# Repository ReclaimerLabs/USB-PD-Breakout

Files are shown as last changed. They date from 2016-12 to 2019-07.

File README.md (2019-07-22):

# Introduction

This board features an FUSB302B as a Type-C Port Management (TCPM) chip. You can purchase one on [Tindie](https://www.tindie.com/products/ReclaimerLabs/usb-type-c-power-delivery-phy-breakout-board/). 

# Features

The FUSB302B is a fully-capable USB Power Delivery device. The power header is rated to 100 W (20 V at 5 A) if both Vbus pins are used along with two ground pins. The FUSB302B's max I2C clock frequency is 1 MHz. 

# Example Usage

Example code for use with Arduino can be found [here](https://github.com/graycatlabs/usb-c-arduino/tree/master/usb-c-demo). The [USB-C Explorer](https://github.com/ReclaimerLabs/USB-C-Explorer/tree/master/firmware/USB-C%20Explorer) also uses the same chip. 

Here are the connections you will need. 

* Breakout Pin -> Arduino Pin
* GND -> GND
* Vbus -> Vin (power to the Arduino, regulated down to +5V)
* Vpu -> IOREF (power for pullups for I2C and interrupt)
* VDD -> 3.3V (power for the FUSB302B)
* SDA -> SDA
* SCL -> SCL
* INT -> D12
* GND -> GND (for good measure)

# Questions, Comments, and Contributions

Pull requests are welcome. If you have questions or comments, you can email me directly at jason@reclaimerlabs.com.

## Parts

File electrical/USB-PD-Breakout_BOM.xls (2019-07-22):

Item # | Quantity | Reference | Type | Footprint | Manufacturer | Manufacturer Part Number | Supplier 1 | Supplier 1 Part Number
5 | 1 | C1 | SMD | Capacitors_SMD:C_1206 | Samsung Electro-Mechanics | CL31A106KAHNNNE | Digikey | 1276-1075-1-ND
6 | 2 | C2, C4 | SMD | Capacitors_SMD:C_0603 | Samsung Electro-Mechanics | CL10B104KB8NNNC | Digikey | 1276-1000-1-ND
7 | 1 | C3 | SMD | Capacitors_SMD:C_0805 | Samsung Electro-Mechanics | CL21B105KOFNNNG | Digikey | 1276-6471-1-ND
1 | 2 | C5, C6 | SMD | Capacitors_SMD:C_0603 | Yageo | CC0603KRX7R9BB471 | Digikey | 311-1078-1-ND
2 | 1 | J1 | SMD | Reclaimer_Labs:USB-C_Female_105450-0101 | Molex | 1054500101 | Digikey | WM12856CT-ND
8 | 1 | J2 | SMD | Reclaimer_Labs:USB_Micro-B_10118193 | Amphenol ICC (FCI) | 10118193-0001LF | Digikey | 609-4616-1-ND
9 | 1 | J3 | Thru-hole | Socket_Strips:Socket_Strip_Straight_2x03 | Amphenol ICC (FCI) | 67997-206HLF | Digikey | 609-3234-ND
10 | 1 | J4 | Thru-hole | Socket_Strips:Socket_Strip_Straight_1x08 | Amphenol ICC (FCI) | 77311-818-08LF | Digikey | 609-5130-ND
4 | 3 | R1, R2, R3 | SMD | Capacitors_SMD:C_0603 | Yageo | RC0603FR-074K7L | Digikey | 311-4.70KHRCT-ND
3 | 1 | U1 | SMD | Reclaimer_Labs:MLP_14 | ON Semiconductor | FUSB302BMPX | Digikey | FUSB302BMPXCT-ND

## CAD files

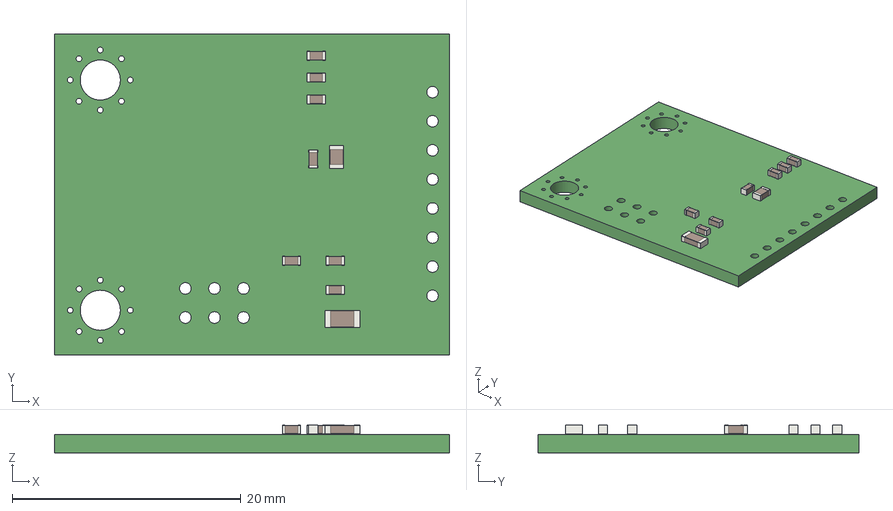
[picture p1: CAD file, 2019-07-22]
electrical/USB-PD-Breakout.step
34.5 x 28.0 x 2.43 mm
Socket_Strip_Straight_2x03
Socket_Strip_Straight_1x08_Pitch2.54mm

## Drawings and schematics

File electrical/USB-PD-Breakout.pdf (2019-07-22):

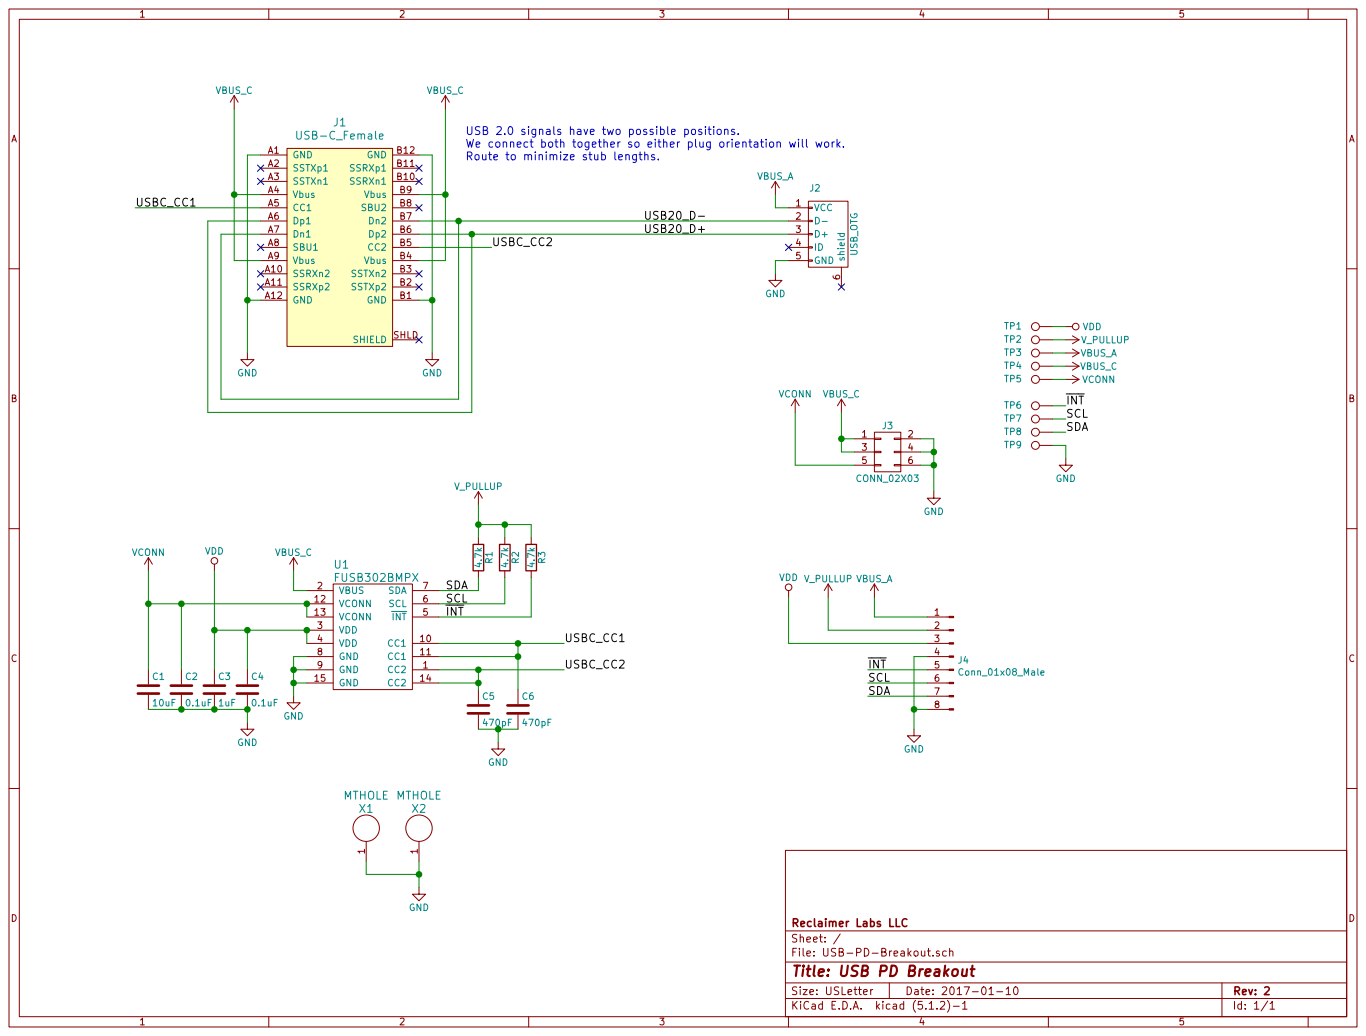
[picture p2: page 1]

V_PULLUP USB 2.0 signals have two possible positions.
We connect both together so either plug orientation will work.
Route to minimize stub lengths.

Id: 1/1 Title: USB PD Breakout File: USB-PD-Breakout.sch Sheet: / Reclaimer Labs LLC

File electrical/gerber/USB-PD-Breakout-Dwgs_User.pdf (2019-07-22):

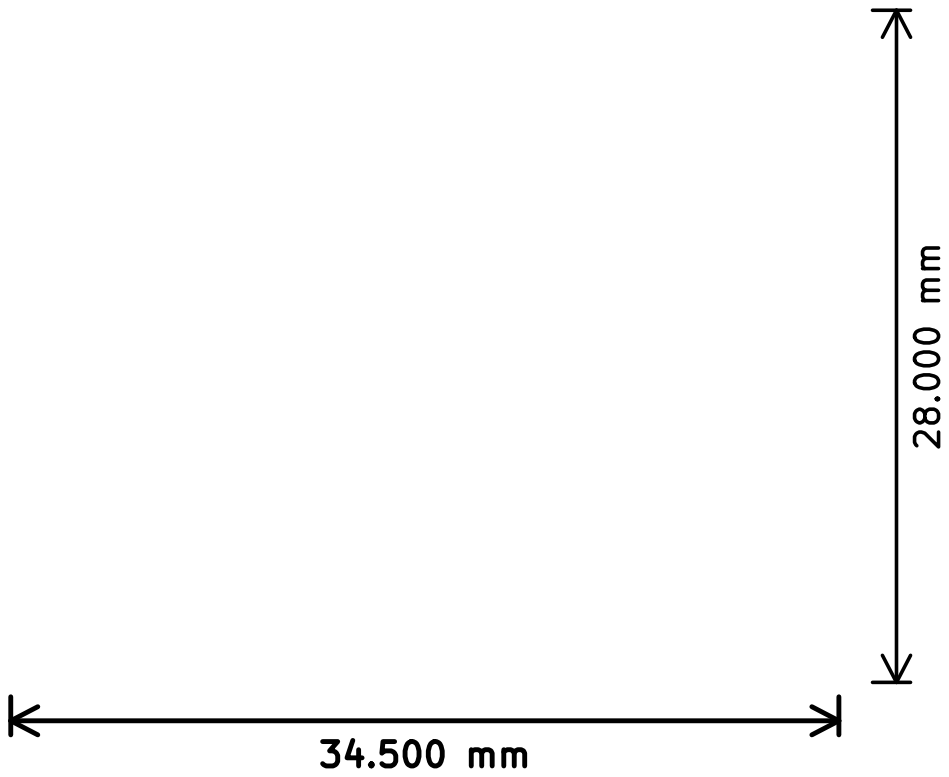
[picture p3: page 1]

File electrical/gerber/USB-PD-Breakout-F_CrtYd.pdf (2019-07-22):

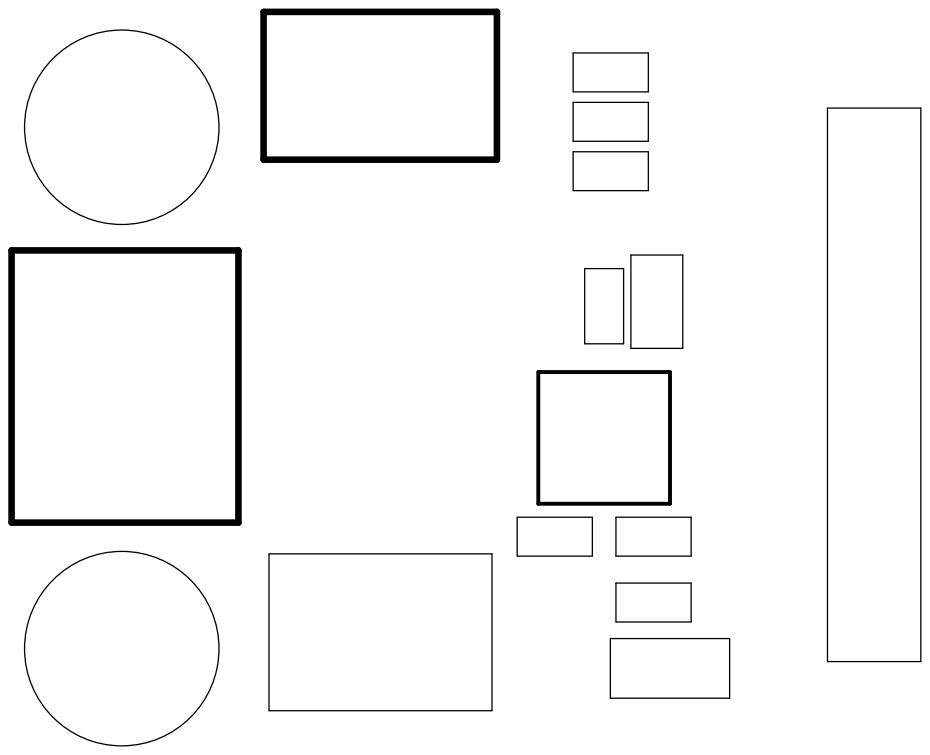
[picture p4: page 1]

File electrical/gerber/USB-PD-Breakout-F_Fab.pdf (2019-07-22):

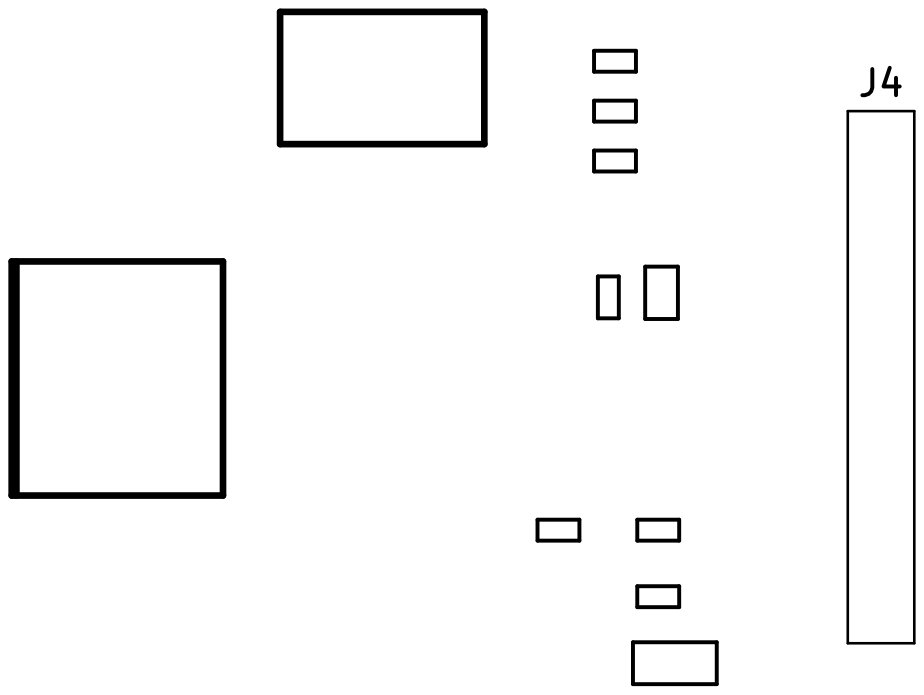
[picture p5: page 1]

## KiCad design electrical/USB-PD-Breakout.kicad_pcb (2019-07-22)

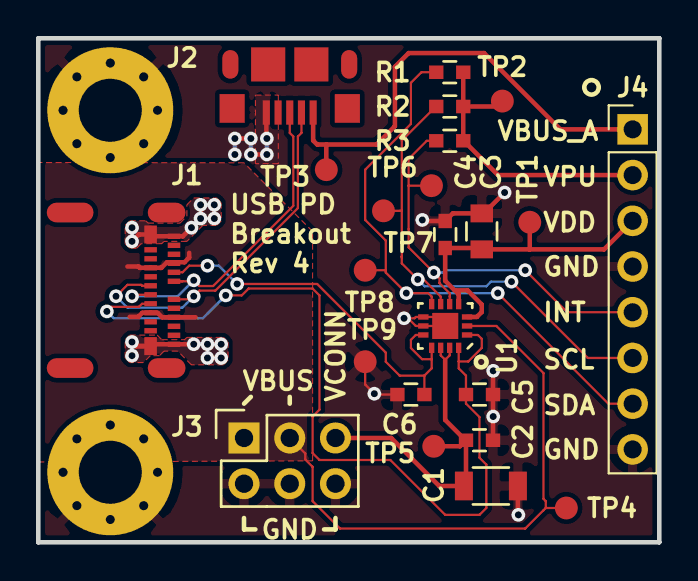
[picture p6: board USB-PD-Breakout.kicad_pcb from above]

Board: 2 copper layers, 34.5 x 28.0 mm, 25 parts (0 on the bottom side), 13 nets.

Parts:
C1: 10uF; C_1206
C2, C4: 0.1uF; C_0603
C3: 1uF; C_0805
C5, C6: 470pF; C_0603
J1: USB-C_Female; USB-C_Female_105450-0101
J2: USB_OTG; USB_Micro-B_10118193
J3: CONN_02X03; Socket_Strip_Straight_2x03
J4: Conn_01x08_Male; Socket_Strip_Straight_1x08_Pitch2.54mm
R1, R2, R3: 4.7k; C_0603
TP1, TP2, TP3, TP4, TP5, TP6, TP7, TP8, TP9: TEST_1P; TP
U1: FUSB302BMPX; MLP_14
X1, X2: MTHOLE; MountingHole_3.5mm_Pad_Via

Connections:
/SCL: J4.6, R2.2, TP7.1, U1.6
/SDA: J4.7, R1.2, TP8.1, U1.7
/USB20_D+: J1.A6, J1.B6, J2.3
/USB20_D-: J1.A7, J1.B7, J2.2
/USBC_CC1: C6.1, J1.A5, U1.10, U1.11
/USBC_CC2: C5.1, J1.B5, U1.1, U1.14
/~INT: J4.5, R3.2, TP6.1, U1.5
GND: C1.2, C2.2, C3.2, C4.2, C5.2, C6.2, J1.A1, J1.A12, J1.B1, J1.B12, J2.5, J3.2, J3.4, J3.6, J4.4, J4.8, TP9.1, U1.8, U1.9, U1.15, X1.1, X2.1
VBUS_A: J2.1, J4.1, TP3.1
VBUS_C: J1.A4, J1.A9, J1.B4, J1.B9, J3.1, J3.3, TP4.1, U1.2
VCONN: C1.1, C2.1, J3.5, TP5.1, U1.12, U1.13
VDD: C3.1, C4.1, J4.3, TP1.1, U1.3, U1.4
V_PULLUP: J4.2, R1.1, R2.1, R3.1, TP2.1

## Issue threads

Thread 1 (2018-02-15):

USB 3 port support?

elggem, 2018-02-15:
Hi (hope this is the best place for this question!),

First of all amazing work, thanks for doing this. This is really the only place on the web I could find of even the possibility of extracting higher amps from USB c via PD...

I am working on a USB C connection cable for my Lacie Rugged Raid, which can only be bus powered from TB2...

The only thing needed in addition to your work would be a USB3 instead of USB2 port. How much work do you think this would be?

Also have you thought about integrating an ATMega into this board for voltage negotiation, so that the user could select voltage and amperage via jumper pads?

Thanks again!!

ReclaimerLabs, 2018-08-07:
Hi elggem,

I just noticed this message. (I'm not the best at using github). You've probably already moved on, but I figured I'd answer just in case.

As for adding a USB3 port, it adds a lot more complexity. More specifically, the USB SuperSpeed lines run at much higher speeds, so routing is tricky and board cost goes up significantly. I have a few ideas for projects that will use it, and I'll see if I can add it to a more specialized breakout board.

As for adding a microcontroller to my breakout board, I've done exactly that. I've released the USB-C Explorer, which uses a SAMD21, similar to the Arduino M0. Right now it will go for up to 20 V if it can, but the firmware can easily be modified. You can check out the design [here ](https://github.com/ReclaimerLabs/USB-C-Explorer) and buy one [here](https://www.tindie.com/products/ReclaimerLabs/usb-c-explorer/).

Sincerely,
Jason

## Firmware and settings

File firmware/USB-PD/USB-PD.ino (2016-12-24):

#include <Wire.h>

const uint8_t PD_ADDR = 0x22;
uint8_t tx_buf[80];
uint8_t rx_buf[80];
uint8_t temp_buf[80];

void sendPacket( \
      uint8_t num_data_objects, \
      uint8_t message_id, \
      uint8_t port_power_role, \
      uint8_t spec_rev, \
      uint8_t port_data_role, \
      uint8_t message_type, \
      uint8_t *data_objects );

void setup() {
  // put your setup code here, to run once:
  Wire.begin();
  Serial.begin(115200);
  Serial.println("Hello");

  setReg(0x0C, 0x01); // Reset FUSB302
  setReg(0x0B, 0x0F); // FULL POWER!
  setReg(0x07, 0x04); // Flush RX
  setReg(0x02, 0x0B); // Switch on MEAS_CC2
  //setReg(0x02, 0x07); // Switch on MEAS_CC1
  setReg(0x03, 0x26); // Enable BMC Tx on CC2
  //setReg(0x03, 0x25); // Enable BMC Tx on CC2
  readAllRegs();
  
  sendPacket( 0, 2, 0, 1, 0, 0x7, NULL );
  delay(1000);
  while ( getReg(0x41) & 0x20 ) {
    delay(1);
  }
  receivePacket();
  while ( getReg(0x41) & 0x20 ) {
    delay(1);
  }
  receivePacket();
  Serial.print("0x");
  Serial.println(getReg(0x41), HEX);
  
  temp_buf[0] = 0b01100100;
  temp_buf[1] = 0b10010000;
  temp_buf[2] = 0b00000001;
  temp_buf[3] = 0b00100000;
  sendPacket( 1, 3, 0, 1, 0, 0x2, temp_buf );
  delay(1000);
  while ( getReg(0x41) & 0x20 ) {
    delay(1);
  }
  receivePacket();
  while ( getReg(0x41) & 0x20 ) {
    delay(1);
  }
  receivePacket();
  

  readAllRegs();

}

void loop() {

  //delay(1000);
}

void readAllRegs() {
  Wire.beginTransmission(PD_ADDR);
  Wire.write(0x01);
  Wire.endTransmission(false);
  Wire.requestFrom((int)PD_ADDR, 16, 1);
  for (int i=1; i<=16; i++) {
    uint8_t c = Wire.read();
    Serial.print("Address: 0x");
    Serial.print(i, HEX);
    Serial.print(", Value: 0x");
    Serial.println(c, HEX);
  }
  
  Wire.beginTransmission(PD_ADDR);
  Wire.write(0x3C);
  Wire.endTransmission(false);
  Wire.requestFrom((int)PD_ADDR, 7, true);
  for (int i=0x3C; i<=0x42; i++) {
    uint8_t c = Wire.read();
    Serial.print("Address: 0x");
    Serial.print(i, HEX);
    Serial.print(", Value: 0x");
    Serial.println(c, HEX);
  }
  
  Serial.println();
  Serial.println();
}

void setReg(uint8_t addr, uint8_t value) {
  Wire.beginTransmission(PD_ADDR);
  Wire.write(addr);
  Wire.write(value);
  Wire.endTransmission(true);
}

uint8_t getReg(uint8_t addr) {
  Wire.beginTransmission(PD_ADDR);
  Wire.write(addr);
  Wire.endTransmission(false);
  Wire.requestFrom((int)PD_ADDR, 1, true);
  return Wire.read();
}

void sendBytes(uint8_t *data, uint16_t length) {
  if (length > 0) {
    Wire.beginTransmission(PD_ADDR);
    Wire.write(0x43);
    for (uint16_t i=0; i<length; i++) {
      Wire.write(data[i]);
    }
    Wire.endTransmission(true);
  }
}

void receiveBytes(uint8_t *data, uint16_t length) {
  if (length > 0) {
    Wire.beginTransmission(PD_ADDR);
    Wire.write(0x43);
    Wire.endTransmission(false);
    Wire.requestFrom((int)PD_ADDR, (int)length, true);
    for (uint16_t i=0; i<length; i++) {
      data[i] = Wire.read();
    }
  }
}

bool receivePacket() {
  uint8_t num_data_objects;
  uint8_t message_id;
  uint8_t port_power_role;
  uint8_t spec_rev;
  uint8_t port_data_role;
  uint8_t message_type;
  
  receiveBytes(rx_buf, 1);
  if (rx_buf[0] != 0xE0) {
    // implement other features later
    Serial.print("FAIL: 0x");
    Serial.println(rx_buf[0], HEX);
    return false;
  }

  receiveBytes(rx_buf, 2);
  
  num_data_objects = ((rx_buf[1] & 0x70) >> 4);
  message_id       = ((rx_buf[1] & 0x0E) >> 1);
  port_power_role  = (rx_buf[1] & 0x01);
  spec_rev         = ((rx_buf[0] & 0xC0) >> 6);
  port_data_role   = ((rx_buf[0] & 0x10) >> 5);
  message_type     = (rx_buf[0] & 0x0F);
  Serial.println("Received SOP Packet");
  Serial.print("Header: 0x");
  Serial.println(*(int *)rx_buf, HEX);
  Serial.print("num_data_objects = ");
  Serial.println(num_data_objects, DEC);
  Serial.print("message_id       = ");
  Serial.println(message_id, DEC);
  Serial.print("port_power_role  = ");
  Serial.println(port_power_role, DEC);
  Serial.print("spec_rev         = ");
  Serial.println(spec_rev, DEC);
  Serial.print("port_data_role   = ");
  Serial.println(port_data_role, DEC);
  Serial.print("message_type     = ");
  Serial.println(message_type, DEC);

  receiveBytes(rx_buf, (num_data_objects*4));
  // each data object is 32 bits
  for (uint8_t i=0; i<num_data_objects; i++) {
    Serial.print("Object: 0x");
    Serial.println(*(long *)(rx_buf+(i*4)), HEX);
  }  

  // CRC-32
  receiveBytes(rx_buf, 4);
  Serial.print("CRC-32: 0x");
  Serial.println(*(long *)rx_buf, HEX);
  Serial.println();

  return true;
}

void sendPacket( \
      uint8_t num_data_objects, \
      uint8_t message_id, \
      uint8_t port_power_role, \
      uint8_t spec_rev, \
      uint8_t port_data_role, \
      uint8_t message_type, \
      uint8_t *data_objects ) {

  uint8_t temp;
  tx_buf[0]  = 0x12; // SOP, see USB-PD2.0 page 108
  tx_buf[1]  = 0x12;
  tx_buf[2]  = 0x12;
  tx_buf[3]  = 0x13;
  tx_buf[4]  = (0x80 | (2 + (4*(num_data_objects & 0x1F))));
  tx_buf[5]  = (message_type & 0x0F);
  tx_buf[5] |= ((port_data_role & 0x01) << 5);
  tx_buf[5] |= ((spec_rev & 0x03) << 6);
  tx_buf[6]  = (port_power_role & 0x01);
  tx_buf[6] |= ((message_id & 0x07) << 1);
  tx_buf[6] |= ((num_data_objects & 0x07) << 4);

  Serial.print("Sending Header: 0x");
  Serial.println(*(int *)(tx_buf+5), HEX);
  Serial.println();

  temp = 7;
  for(uint8_t i=0; i<num_data_objects; i++) {
    tx_buf[temp]   = data_objects[(4*i)];
    tx_buf[temp+1] = data_objects[(4*i)+1];
    tx_buf[temp+2] = data_objects[(4*i)+2];
    tx_buf[temp+3] = data_objects[(4*i)+3];
    temp += 4;
  }

  tx_buf[temp] = 0xFF; // CRC
  tx_buf[temp+1] = 0x14; // EOP
  tx_buf[temp+2] = 0xFE; // TXOFF
/*
  Serial.print("Sending ");
  Serial.print((10 + (4*(num_data_objects & 0x1F))), DEC);
  Serial.println(" bytes.");

  for (uint16_t i=0; i<(10 + (4*(num_data_objects & 0x1F))); i++) {
    Serial.print("0x");
    Serial.println(tx_buf[i], HEX);
  }
  Serial.println();
*/
  temp = getReg(0x06);
  sendBytes(tx_buf, (10+(4*(num_data_objects & 0x1F))) );
  setReg(0x06, (temp | (0x01))); // Flip on TX_START
}

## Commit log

2016-04-30 Version 1
    Rev 1 sent to fab
    [USB-PD-Breakout-B.Cu.gbl, USB-PD-Breakout-B.Mask.gbs, USB-PD-Breakout-B.SilkS.gbo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]
2016-12-24 Updated drl file
    Had to merge the drl files together to accomadate Macrofab
    [USB-PD-Breakout.kicad_pcb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]
2017-04-19 Rev2 Update
    [USB-PD-Breakout-B.Cu.gbl, USB-PD-Breakout-B.Mask.gbs, USB-PD-Breakout-B.SilkS.gbo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]
2019-07-22 Rev 4
    Final Rev 4 design. Simplied headers, shrank board area, and added testpoints for DFM.
    [USB-PD-Breakout-2019-05-30-22-14-38.sch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]
